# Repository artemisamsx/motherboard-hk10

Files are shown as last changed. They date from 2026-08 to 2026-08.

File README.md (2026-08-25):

# Artemisa MSX - Model HK-10 Motherboard

This repository contains the KiCad project files for the Model HK-10 motherboard, part of the **Artemisa** project.

## About Artemisa

Artemisa is a project to design new MSX-1 compatible computers using modern manufacturing
techniques while staying true to the original architecture: a Z80 CPU, discrete memory chips,
and dedicated peripheral ICs (VDP, PSG, PPI, etc.), with no FPGAs involved. The roadmap
includes several different models, each exploring different trade-offs between fidelity,
cost, and ease of assembly.

## The HK-10 model

The HK-10 is based on the **Model 101**, a prototype that was never distributed commercially.
The goal of the HK-10 is to bring that design to the general public as a homebrew-friendly
product, with the constraints and trade-offs typical of the homebrew scene.

"HK" stands for **Homebrew Kit**. The HK-10 is meant to be sold as a kit and assembled by the
user, comprising:

- The motherboard and other PCBs
- A 3D-printed PETG enclosure
- The main chips (CPU, memory, PSG, VDP)
- Passive components (resistors, capacitors, etc.)

### Features

- 2 cartridge slots
- 1 datasette (cassette) port
- 2 joystick ports
- External, cable-connected keyboard port

The HK-10 does **not** include a serial port or a printer port.

### Graphics

The graphics subsystem is implemented on separate PCBs rather than being part of the
motherboard itself, so that users can customize their video output and choose a graphics
chip (TMS9918 vs TMS9928 vs TMS9929). These graphics cards are based on the GFX-9918 card
used in the Model 101 prototype, but with a different form factor and naming, e.g.
`HKG-9918`, `HKG-9929`.

### Memory

The HK-10 uses SRAM instead of DRAM. For the memory sizes involved, SRAM is simpler, cheaper
and easier to source than DRAM, at the cost of some board space.

### Design philosophy

The HK-10 aims to be the simplest and most didactic model in the Artemisa lineup. To that
end, it avoids any programmable logic devices (PLDs, PALs, GALs, etc.) in favor of discrete
logic chips, consistent with how the original MSX computers were designed in the 1980s.

### Differences from the Model 101 prototype

- **Form factor**: the HK-10 uses a different, more compact form factor than the 101.
- **Power supply**: the HK-10 has its own integrated AC/DC adapter providing 5V, 12V and -12V,
  whereas the 101 was only powered externally at 5V.
- **Simplified circuits**: some circuits have been simplified compared to the 101, namely the
  clock generation and the power-on reset (PoR) circuit.
- **No integrated keyboard**: unlike most MSX computers (and most microcomputers of that era),
  the HK-10 does not have a keyboard built into the case. The keyboard is a separate unit
  connected via cable to a port on the motherboard.

## Repository layout

The schematic is split into sheets by functional block:

| File | Contents |
|---|---|
| `motherboard-hk10.kicad_sch` | Top-level sheet |
| `cpu.kicad_sch` | Z80 CPU |
| `ram.kicad_sch` | SRAM |
| `rom.kicad_sch` | ROM |
| `ppi.kicad_sch` | Programmable Peripheral Interface (keyboard, joysticks, cassette control) |
| `psg.kicad_sch` | Programmable Sound Generator |
| `clock.kicad_sch` | Clock generation |
| `decoding.kicad_sch` | Address decoding |
| `power.kicad_sch` | Power supply and power-on reset |
| `slots.kicad_sch` | Cartridge slots |
| `keyboard.kicad_sch` | External keyboard connector |
| `cassette.kicad_sch` | Datasette port |

`motherboard-hk10.kicad_pcb` contains the PCB layout, and `simulation/` contains SPICE
simulations used to validate specific circuits (power-on reset, clock generation, video
output filtering, etc.).

See [CHANGELOG.md](CHANGELOG.md) for a history of board revisions.

## Key components

- **Clock generator**: [Epson SG-615P / SG-531P][1], a packaged crystal oscillator (SPXO)
  used to generate the master clock.

## License

This project is licensed under the [TAPR Open Hardware License](LICENSE.txt).

---

[1]: https://www.mouser.com/datasheet/2/137/SG_615P_en-1880245.pdf "Epson SG-615P / SG-531P datasheet"

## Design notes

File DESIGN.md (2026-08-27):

# HK-10 Design Notes

This document records relevant design decisions and considerations for the HK-10 motherboard,
organized by functional area. It complements the schematics and [README.md](README.md) by
capturing the *why* behind choices that aren't obvious from the design files alone.

## Power management

### AC/DC adapter

The HK-10 integrates an AC/DC power adapter inside the enclosure rather than relying on an
external wall-wart, unlike the Model 101 prototype. The adapter is a third-party module, not
a custom design: the [Meanwell RT-50B][1] was chosen. It provides the 5V, 12V and -12V
rails required by the board.

Mains enters through a panel-mounted IEC 320 C14 inlet with an integrated fuse holder and
rocker switch, specifically the Filn AC-14-F15 (an Asian vendor part). The C14 is used
rather than a two-pole inlet so the enclosure carries a protective-earth connection, which
the RT-50B requires.

The adapter connects to the motherboard through a cable fitted with a JST connector. We
settled on **JST-XH** (2.5mm pitch, 4 positions: +5V, +12V, -12V, GND) over other JST
families such as PH: XH terminals are rated for ~3A per contact, giving headroom over PH's
~2A, and XH is the de-facto standard for RC/LiPo balance connectors, which makes it easy to
source pre-crimped cable assemblies from generic vendors rather than specialized suppliers
like Mouser or Digikey.

The pinout, matching the wire colors of the generic pre-crimped kits used, is:

| Pin | Signal | Wire color |
|---|---|---|
| 1 | GND | Black |
| 2 | +5V | Red |
| 3 | -12V | White |
| 4 | +12V | Yellow |

One caveat worth recording: off-the-shelf "JST-XH balance cables" from the RC hobby market
are typically wired with 26-28 AWG, since balance leads only carry sensing current, not
power. For this power cable we need 22 AWG (or better) so the wire itself doesn't become the
bottleneck. Pre-crimped 4-pin XH kits with 22 AWG wire are readily available on generic
retail (e.g. Amazon Spain), so this doesn't require a specialized crimping tool or sourcing
loose terminals.

With a single shared GND return, the worst-case combined return current is the sum of the
+5V, +12V and -12V draws. The MSX standard caps the cartridge slots' power budget per slot
at 300mA (+5V), 50mA (+12V) and 50mA (-12V)[3]. With the HK-10's 2 cartridge slots, and the
~500mA the motherboard itself draws on +5V (per the Model 101 prototype, which doesn't use
+12V/-12V at all), the absolute worst case is ~1.1A on +5V and 100mA each on +12V/-12V — a
combined return well within the XH terminal's ~3A rating and the 22 AWG wire's capacity, so
a single GND pin is sufficient without needing a 5-pin connector with a doubled-up return.

The RT-50B is a switching (SMPS) power supply, so its output rails can carry significant
ripple and switching noise. On its own 5V rail, this noise is prone to leaking into the VDP's
analog video output, resulting in a visibly noisy picture. To mitigate this, we are evaluating
deriving a clean 5V supply for the VDP from the RT-50B's 12V rail through a linear regulator
(7805) instead of using the RT-50B's 5V rail directly. A linear regulator rejects the
switching noise present on the 12V rail, at the cost of the extra heat dissipated by the
regulator. This is not settled yet, but the 7805 would most likely live on the HKG-99xx
graphics card rather than on the motherboard.

### Power-on reset (PoR)

The power-on reset circuit is built around the [MIC1232][2] from Microchip. It was
chosen mainly for its ease of use combined with good availability, particularly in DIP
package, which matters for a kit meant to be hand-assembled by end users.

## Clock generation

The master clock is generated with a packaged crystal oscillator IC, the Epson SG-615P /
SG-531P, instead of a discrete crystal driven by an unbuffered inverter (74HCU04) with its
typical feedback network (bias/feedback resistor, series damping resistor, and symmetric
load capacitors). The oscillator IC integrates the crystal, feedback network and load
capacitors internally and outputs a ready-made digital clock signal, which removes several
discrete components (crystal, two load capacitors, two resistors) and the oscillator gate
from the board. The divide-by-2 stage that derives `PSGCLK` from `CLK` for the PSG is
unaffected by this change.

The oscillator's `CLK` output is buffered before fanning out to the CPU, the cartridge
slots, the power-on reset sync logic and the `PSGCLK` divider, rather than driving all of
that directly from the oscillator's output pin. Buffering keeps the oscillator isolated
from a net that is exposed on the (hot-pluggable) cartridge slot connectors, and gives
some headroom against the oscillator's fairly light guaranteed output drive (`IOH` = -400
µA min. per the datasheet). The buffer is a spare gate on `U14`, a `74HC08` (quad 2-input
AND) already used for address-decoding logic, wired as a non-inverting buffer by tying one
input permanently high. This avoids adding a new IC just for buffering — none of the
existing inverter packages on the board had a spare gate, but this AND gate did. Signal
polarity doesn't matter here (nothing on this board has a phase relationship to preserve
against the raw oscillator output), so a single gate is enough; there's no need for a
second inversion. Checked against the TI SN74HC08 datasheet, this buffer neither hurts
fanout (both parts are rated for 10 LSTTL loads) nor meaningfully degrades the clock edges
(its rise/fall time is comparable to the oscillator's own, and negligible next to the
~279 ns clock period at 3.579545 MHz).

## Enclosure layout

The enclosure targets a 25x33.5cm internal perimeter. The motherboard, at 24x18cm, sits
centered and pushed against the front end of the enclosure.

On that front end are the joystick ports and the keyboard port. The cassette port sits on the
right-hand side. The cartridge slots are centered on the motherboard.

The rear end of the enclosure houses the RT-50B power supply and the HKG-99xx graphics card.
The motherboard and the graphics card are connected by a 50-pin IDC cable.

### Cartridge alignment guides

Rather than relying on a bare slot cut into the enclosure shell with a spring to guide
cartridges into their card-edge connectors (as in the Model 101 prototype), the HK-10
enclosure will include a pair of 3D-printed guide housings, one per cartridge slot. Each
housing is tub-shaped, covering the full footprint of the cartridge on top of the
motherboard with an opening for the card-edge connector, and with internal ribs matching
the notches standard on MSX cartridges to physically block reversed insertion, which could
otherwise damage the cartridge's own edge connector.

With a cartridge fully seated in its slot, there's a measured 5mm clearance between the
bottom of the cartridge shell and the motherboard PCB, which the guide housing's floor
occupies.

Each guide housing is fastened to the motherboard with 2x M3 screws, which also pass
through into the enclosure shell, tying housing, PCB and enclosure into a single rigid
assembly. This accounts for 4 of the board's mounting holes (2 per slot), placed close to
each slot connector, one at each end. Sitting directly against the connectors, these give
the slot area — the heaviest, most heavily stressed part of the board — more direct
support than a single mounting hole at the board's geometric center would, so no separate
central mounting hole is needed.

---

[1]: http://www.meanwelljapan.com/upload/pdf/RT-50/RT-50-SPEC.PDF "Meanwell RT-50B datasheet"
[2]: https://www.microchip.com/en-us/product/mic1232 "Microchip MIC1232 product page"
[3]: https://sysadminmosaic.ru/_media/msx/msx_technical_data_book/msx_technical_data_book_text.pdf "MSX Technical Data Book, section 1.5.4 Cartridge Power Capacity"

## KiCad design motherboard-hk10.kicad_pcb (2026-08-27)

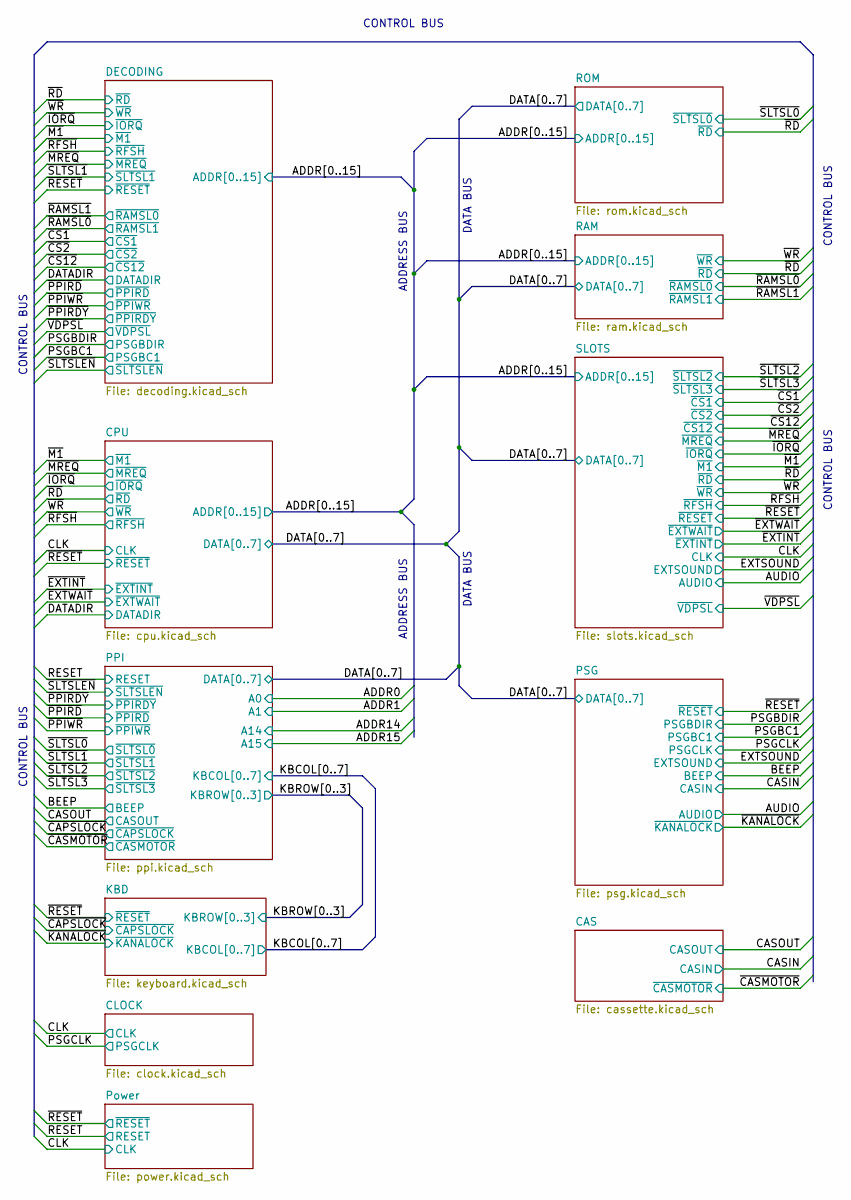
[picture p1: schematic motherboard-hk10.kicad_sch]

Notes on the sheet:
CONTROL BUS
ADDRESS BUS
DATA BUS

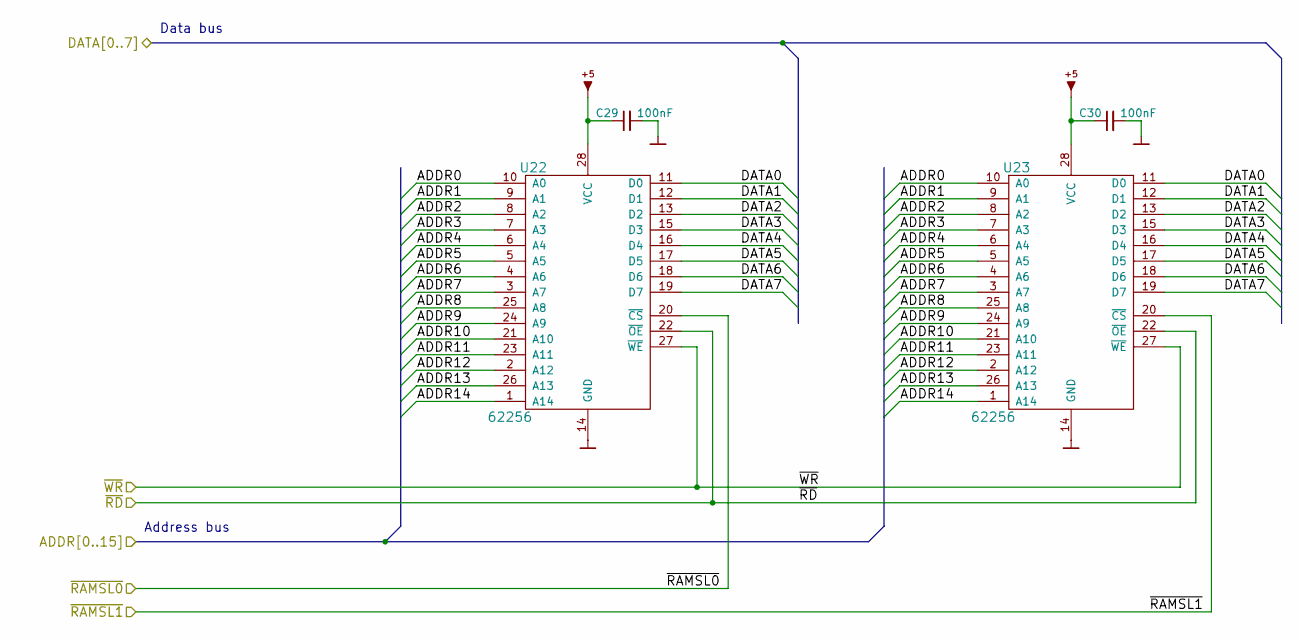
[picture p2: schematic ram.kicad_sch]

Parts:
C29, C30: 100nF; C_Disc_D5.0mm_W2.5mm_P2.50mm
U22, U23: 62256; DIP-28_W15.24mm_Socket

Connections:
/ADDR0: U22.10 (A0), U23.10 (A0); also elsewhere on the board
/ADDR1: U22.9 (A1), U23.9 (A1); also elsewhere on the board
/ADDR2: U22.8 (A2), U23.8 (A2); also elsewhere on the board
/ADDR3: U22.7 (A3), U23.7 (A3); also elsewhere on the board
/ADDR4: U22.6 (A4), U23.6 (A4); also elsewhere on the board
/ADDR5: U22.5 (A5), U23.5 (A5); also elsewhere on the board
/ADDR6: U22.4 (A6), U23.4 (A6); also elsewhere on the board
/ADDR7: U22.3 (A7), U23.3 (A7); also elsewhere on the board
/ADDR8: U22.25 (A8), U23.25 (A8); also elsewhere on the board
/ADDR9: U22.24 (A9), U23.24 (A9); also elsewhere on the board
/ADDR10: U22.21 (A10), U23.21 (A10); also elsewhere on the board
/ADDR11: U22.23 (A11), U23.23 (A11); also elsewhere on the board
/ADDR12: U22.2 (A12), U23.2 (A12); also elsewhere on the board
/ADDR13: U22.26 (A13), U23.26 (A13); also elsewhere on the board
/ADDR14: U22.1 (A14), U23.1 (A14); also elsewhere on the board
/DATA0: U22.11 (D0), U23.11 (D0); also elsewhere on the board
/DATA1: U22.12 (D1), U23.12 (D1); also elsewhere on the board
/DATA2: U22.13 (D2), U23.13 (D2); also elsewhere on the board
/DATA3: U22.15 (D3), U23.15 (D3); also elsewhere on the board
/DATA4: U22.16 (D4), U23.16 (D4); also elsewhere on the board
/DATA5: U22.17 (D5), U23.17 (D5); also elsewhere on the board
/DATA6: U22.18 (D6), U23.18 (D6); also elsewhere on the board
/DATA7: U22.19 (D7), U23.19 (D7); also elsewhere on the board
/~RAMSL0: U22.20 (~CS); also elsewhere on the board
/~RAMSL1: U23.20 (~CS); also elsewhere on the board
/~RD: U22.22 (~OE), U23.22 (~OE); also elsewhere on the board
/~WR: U22.27 (~WE), U23.27 (~WE); also elsewhere on the board
GND: C29.2, C30.2, U22.14 (GND), U23.14 (GND); also elsewhere on the board
VCC: C29.1, C30.1, U22.28 (VCC), U23.28 (VCC); also elsewhere on the board

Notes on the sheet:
Data bus
Address bus

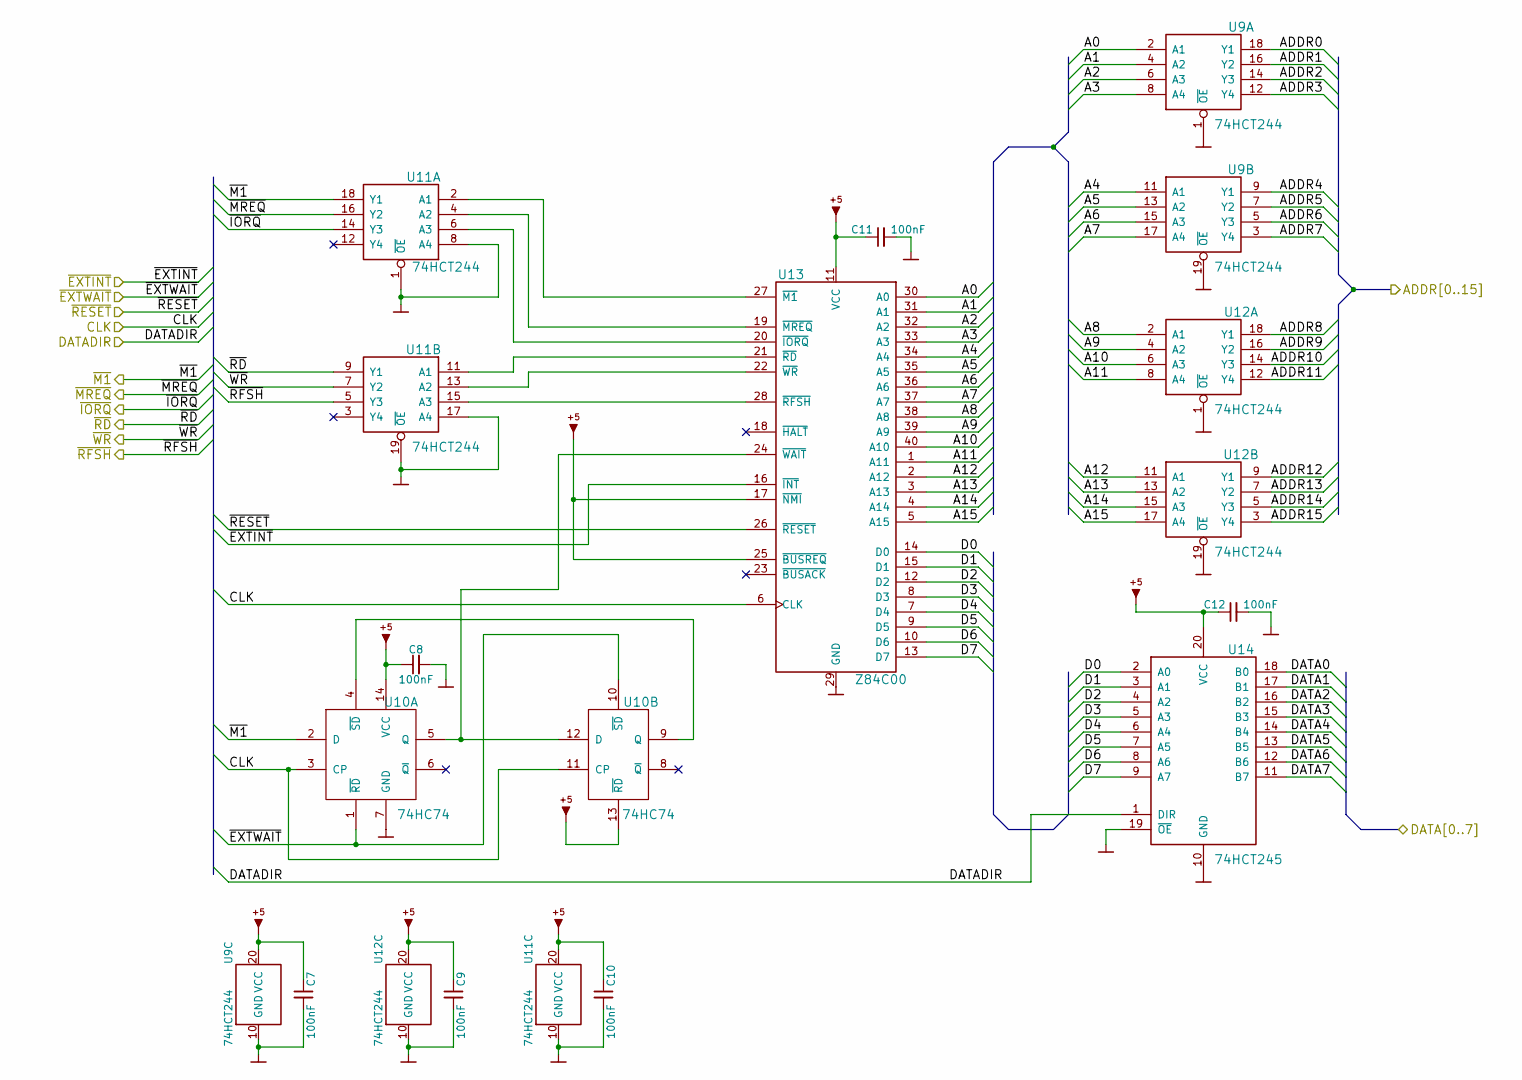
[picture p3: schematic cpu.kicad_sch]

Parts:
C7, C8, C9, C10, C11, C12: 100nF; C_Disc_D5.0mm_W2.5mm_P2.50mm
U9, U11, U12: 74HCT244; DIP-20_W7.62mm
U10: 74HC74; DIP-14_W7.62mm
U13: Z84C00; DIP-40_W15.24mm_Socket
U14: 74HCT245; DIP-20_W7.62mm

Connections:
/ADDR0: U9.18 (Y1); also elsewhere on the board
/ADDR1: U9.16 (Y2); also elsewhere on the board
/ADDR2: U9.14 (Y3); also elsewhere on the board
/ADDR3: U9.12 (Y4); also elsewhere on the board
/ADDR4: U9.9 (Y1); also elsewhere on the board
/ADDR5: U9.7 (Y2); also elsewhere on the board
/ADDR6: U9.5 (Y3); also elsewhere on the board
/ADDR7: U9.3 (Y4); also elsewhere on the board
/ADDR8: U12.18 (Y1); also elsewhere on the board
/ADDR9: U12.16 (Y2); also elsewhere on the board
/ADDR10: U12.14 (Y3); also elsewhere on the board
/ADDR11: U12.12 (Y4); also elsewhere on the board
/ADDR12: U12.9 (Y1); also elsewhere on the board
/ADDR13: U12.7 (Y2); also elsewhere on the board
/ADDR14: U12.5 (Y3); also elsewhere on the board
/ADDR15: U12.3 (Y4); also elsewhere on the board
/CLK: U10.3 (CP), U10.11 (CP), U13.6 (CLK); also elsewhere on the board
/CPU/A0: U9.2 (A1), U13.30 (A0)
/CPU/A1: U9.4 (A2), U13.31 (A1)
/CPU/A2: U9.6 (A3), U13.32 (A2)
/CPU/A3: U9.8 (A4), U13.33 (A3)
/CPU/A4: U9.11 (A1), U13.34 (A4)
/CPU/A5: U9.13 (A2), U13.35 (A5)
/CPU/A6: U9.15 (A3), U13.36 (A6)
/CPU/A7: U9.17 (A4), U13.37 (A7)
/CPU/A8: U12.2 (A1), U13.38 (A8)
/CPU/A9: U12.4 (A2), U13.39 (A9)
/CPU/A10: U12.6 (A3), U13.40 (A10)
/CPU/A11: U12.8 (A4), U13.1 (A11)
/CPU/A12: U12.11 (A1), U13.2 (A12)
/CPU/A13: U12.13 (A2), U13.3 (A13)
/CPU/A14: U12.15 (A3), U13.4 (A14)
/CPU/A15: U12.17 (A4), U13.5 (A15)
/CPU/D0: U13.14 (D0), U14.2 (A0)
/CPU/D1: U13.15 (D1), U14.3 (A1)
/CPU/D2: U13.12 (D2), U14.4 (A2)
/CPU/D3: U13.8 (D3), U14.5 (A3)
/CPU/D4: U13.7 (D4), U14.6 (A4)
/CPU/D5: U13.9 (D5), U14.7 (A5)
/CPU/D6: U13.10 (D6), U14.8 (A6)
/CPU/D7: U13.13 (D7), U14.9 (A7)
/DATA0: U14.18 (B0); also elsewhere on the board
/DATA1: U14.17 (B1); also elsewhere on the board
/DATA2: U14.16 (B2); also elsewhere on the board
/DATA3: U14.15 (B3); also elsewhere on the board
/DATA4: U14.14 (B4); also elsewhere on the board
/DATA5: U14.13 (B5); also elsewhere on the board
/DATA6: U14.12 (B6); also elsewhere on the board
/DATA7: U14.11 (B7); also elsewhere on the board
/DATADIR: U14.1 (DIR); also elsewhere on the board
/~EXTINT: U13.16 (~INT); also elsewhere on the board
/~EXTWAIT: U10.1 (~RD), U10.10 (~SD); also elsewhere on the board
/~IORQ: U11.14 (Y3); also elsewhere on the board
/~M1: U10.2 (D), U11.18 (Y1); also elsewhere on the board
/~MREQ: U11.16 (Y2); also elsewhere on the board
/~RD: U11.9 (Y1); also elsewhere on the board
/~RESET: U13.26 (~RESET); also elsewhere on the board
/~RFSH: U11.5 (Y3); also elsewhere on the board
/~WR: U11.7 (Y2); also elsewhere on the board
GND: C7.2, C8.2, C9.2, C10.2, C11.2, C12.2, U9.1 (~OE), U9.10 (GND), U9.19 (~OE), U10.7 (GND), U11.1 (~OE), U11.8 (A4), U11.10 (GND), U11.17 (A4), U11.19 (~OE), U12.1 (~OE), U12.10 (GND), U12.19 (~OE), U13.29 (GND), U14.10 (GND), U14.19 (~OE); also elsewhere on the board
unnamed: U10.5 (Q), U10.12 (D), U13.24 (~WAIT)
unnamed: U10.4 (~SD), U10.9 (Q)
unnamed: U11.2 (A1), U13.27 (~M1)
unnamed: U11.4 (A2), U13.19 (~MREQ)
unnamed: U11.6 (A3), U13.20 (~IORQ)
unnamed: U11.11 (A1), U13.21 (~RD)
unnamed: U11.13 (A2), U13.22 (~WR)
unnamed: U11.15 (A3), U13.28 (~RFSH)
VCC: C7.1, C8.1, C9.1, C10.1, C11.1, C12.1, U9.20 (VCC), U10.13 (~RD), U10.14 (VCC), U11.20 (VCC), U12.20 (VCC), U13.11 (VCC), U13.17 (~NMI), U13.25 (~BUSREQ), U14.20 (VCC); also elsewhere on the board

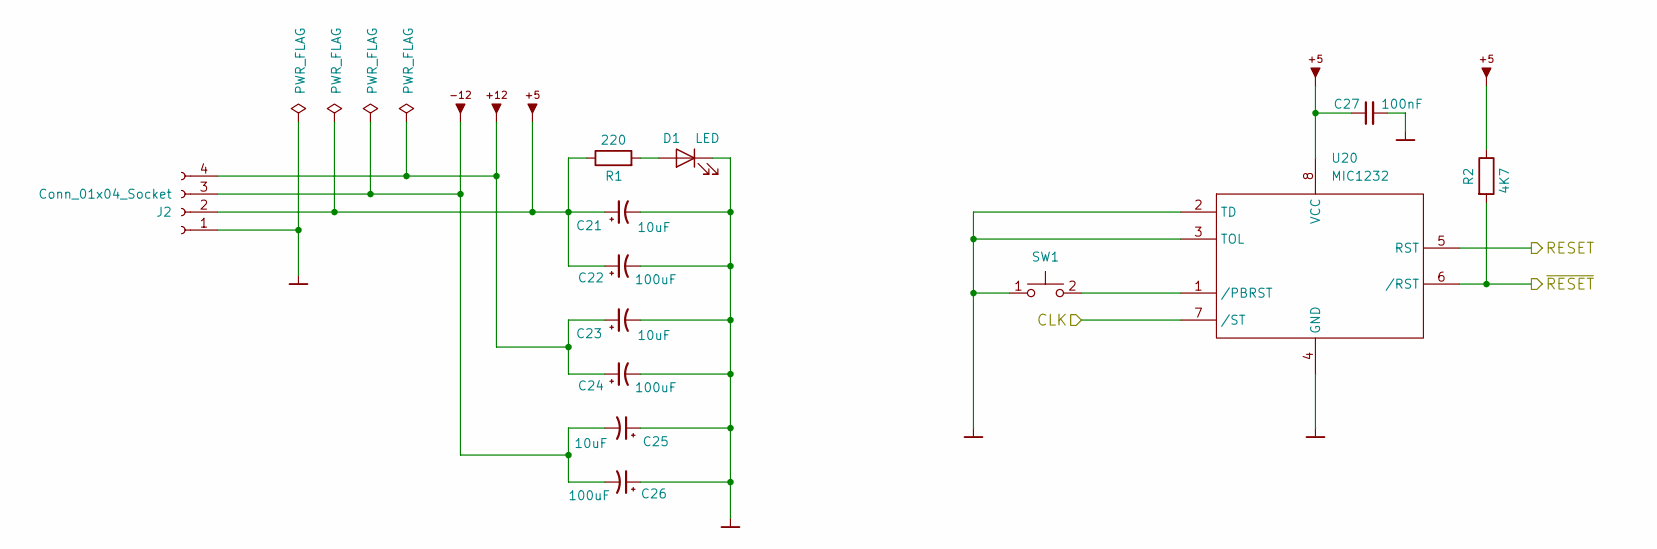
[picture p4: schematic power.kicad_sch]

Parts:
C21, C23, C25: 10uF; CP_Radial_D4.0mm_P2.00mm
C22, C24, C26: 100uF; CP_Radial_D5.0mm_P2.50mm
C27: 100nF; C_Disc_D5.0mm_W2.5mm_P2.50mm
D1: LED; PinHeader_1x02_P2.54mm_Vertical
J2: Conn_01x04_Socket; JST_XH_B4B-XH-A_1x04_P2.50mm_Vertical
R1: 220; R_Axial_DIN0207_L6.3mm_D2.5mm_P10.16mm_Horizontal
R2: 4K7; R_Axial_DIN0207_L6.3mm_D2.5mm_P10.16mm_Horizontal
SW1: Push_button; Push_button_angled
U20: MIC1232; DIP-8_W7.62mm

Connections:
12V: C23.1, C24.1, J2.4; also elsewhere on the board
-12V: C25.2, C26.2, J2.3; also elsewhere on the board
/CLK: U20.7 (/ST); also elsewhere on the board
/RESET: U20.5 (RST); also elsewhere on the board
/~RESET: R2.2, U20.6 (/RST); also elsewhere on the board
GND: C21.2, C22.2, C23.2, C24.2, C25.1, C26.1, C27.2, D1.2 (K), J2.1, SW1.1, U20.2 (TD), U20.3 (TOL), U20.4 (GND); also elsewhere on the board
unnamed: D1.1 (A), R1.2
unnamed: SW1.2, U20.1 (/PBRST)
VCC: C21.1, C22.1, C27.1, J2.2, R1.1, R2.1, U20.8 (VCC); also elsewhere on the board

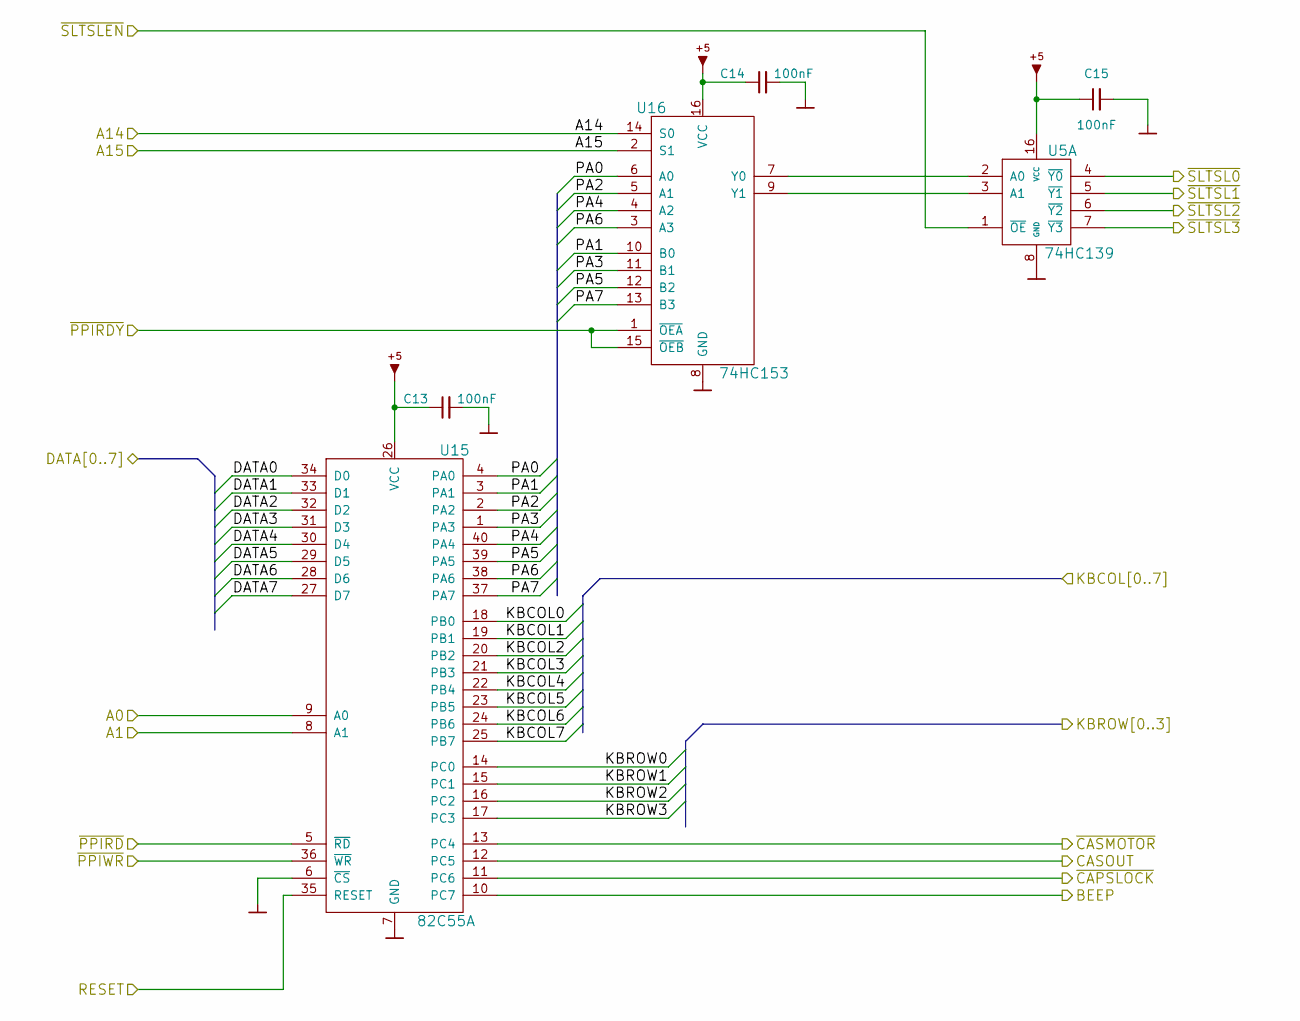
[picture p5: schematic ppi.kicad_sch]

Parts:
C13, C14, C15: 100nF; C_Disc_D5.0mm_W2.5mm_P2.50mm
U5: 74HC139; DIP-16_W7.62mm
U15: 82C55A; DIP-40_W15.24mm_Socket
U16: 74HC153; DIP-16_W7.62mm

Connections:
/ADDR0: U15.9 (A0); also elsewhere on the board
/ADDR1: U15.8 (A1); also elsewhere on the board
/ADDR14: U16.14 (S0); also elsewhere on the board
/ADDR15: U16.2 (S1); also elsewhere on the board
/BEEP: U15.10 (PC7); also elsewhere on the board
/CASOUT: U15.12 (PC5); also elsewhere on the board
/DATA0: U15.34 (D0); also elsewhere on the board
/DATA1: U15.33 (D1); also elsewhere on the board
/DATA2: U15.32 (D2); also elsewhere on the board
/DATA3: U15.31 (D3); also elsewhere on the board
/DATA4: U15.30 (D4); also elsewhere on the board
/DATA5: U15.29 (D5); also elsewhere on the board
/DATA6: U15.28 (D6); also elsewhere on the board
/DATA7: U15.27 (D7); also elsewhere on the board
/KBCOL0: U15.18 (PB0); also elsewhere on the board
/KBCOL1: U15.19 (PB1); also elsewhere on the board
/KBCOL2: U15.20 (PB2); also elsewhere on the board
/KBCOL3: U15.21 (PB3); also elsewhere on the board
/KBCOL4: U15.22 (PB4); also elsewhere on the board
/KBCOL5: U15.23 (PB5); also elsewhere on the board
/KBCOL6: U15.24 (PB6); also elsewhere on the board
/KBCOL7: U15.25 (PB7); also elsewhere on the board
/KBROW0: U15.14 (PC0); also elsewhere on the board
/KBROW1: U15.15 (PC1); also elsewhere on the board
/KBROW2: U15.16 (PC2); also elsewhere on the board
/KBROW3: U15.17 (PC3); also elsewhere on the board
/PPI/PA0: U15.4 (PA0), U16.6 (A0)
/PPI/PA1: U15.3 (PA1), U16.10 (B0)
/PPI/PA2: U15.2 (PA2), U16.5 (A1)
/PPI/PA3: U15.1 (PA3), U16.11 (B1)
/PPI/PA4: U15.40 (PA4), U16.4 (A2)
/PPI/PA5: U15.39 (PA5), U16.12 (B2)
/PPI/PA6: U15.38 (PA6), U16.3 (A3)
/PPI/PA7: U15.37 (PA7), U16.13 (B3)
/RESET: U15.35 (RESET); also elsewhere on the board
/~CAPSLOCK: U15.11 (PC6); also elsewhere on the board
/~CASMOTOR: U15.13 (PC4); also elsewhere on the board
/~PPIRDY: U16.1 (~OEA), U16.15 (~OEB); also elsewhere on the board
/~PPIRD: U15.5 (~RD); also elsewhere on the board
/~PPIWR: U15.36 (~WR); also elsewhere on the board
/~SLTSL0: U5.4 (~Y0); also elsewhere on the board
/~SLTSL1: U5.5 (~Y1); also elsewhere on the board
/~SLTSL2: U5.6 (~Y2); also elsewhere on the board
/~SLTSL3: U5.7 (~Y3); also elsewhere on the board
/~SLTSLEN: U5.1 (~OE); also elsewhere on the board
GND: C13.2, C14.2, C15.2, U5.8 (GND), U15.6 (~CS), U15.7 (GND), U16.8 (GND); also elsewhere on the board
unnamed: U5.2 (A0), U16.7 (Y0)
unnamed: U5.3 (A1), U16.9 (Y1)
VCC: C13.1, C14.1, C15.1, U5.16 (VCC), U15.26 (VCC), U16.16 (VCC); also elsewhere on the board

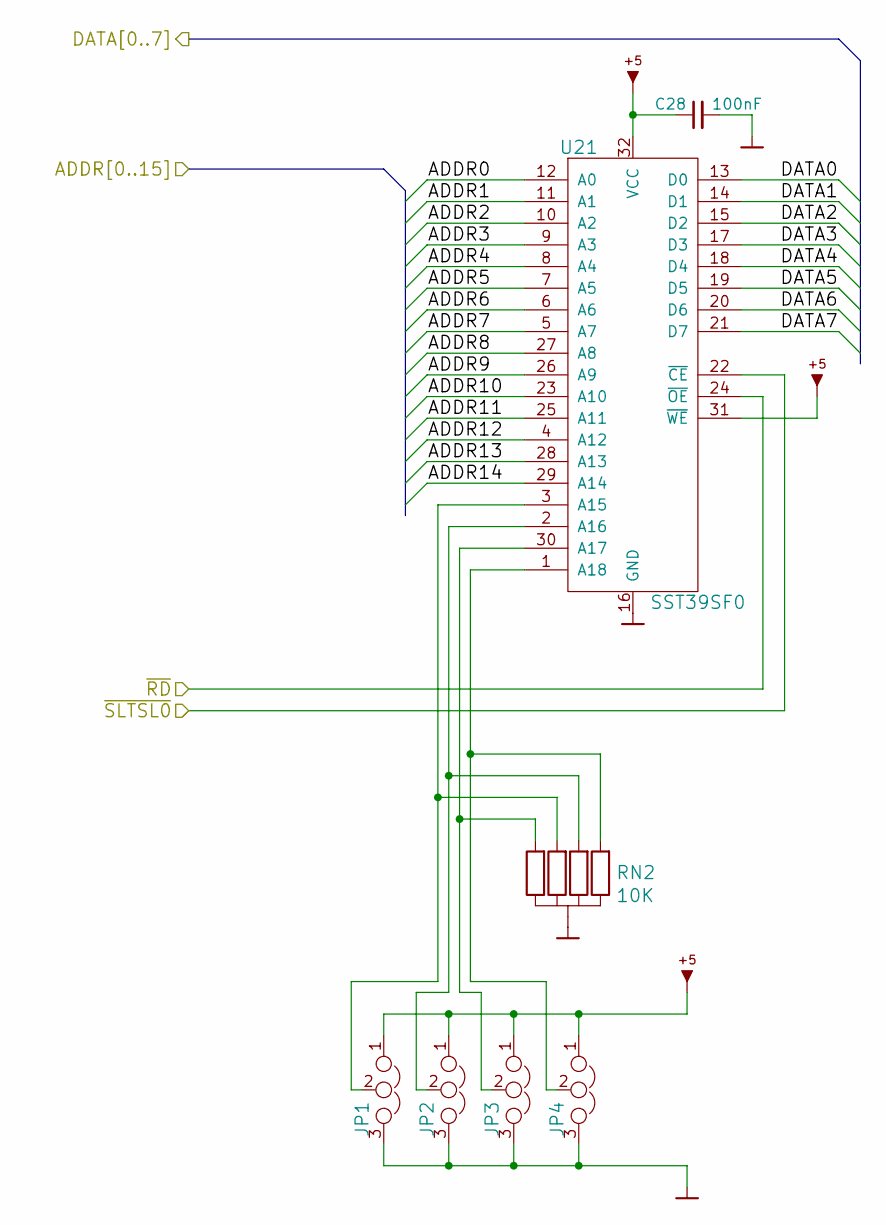
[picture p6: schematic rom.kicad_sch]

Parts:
C28: 100nF; C_Disc_D5.0mm_W2.5mm_P2.50mm
JP1, JP2, JP3, JP4: Jumper; PinHeader_1x03_P2.54mm_Vertical
RN2: 10K; R_Array_SIP5
U21: SST39SF0; DIP-32_W15.24mm_Socket

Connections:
/ADDR0: U21.12 (A0); also elsewhere on the board
/ADDR1: U21.11 (A1); also elsewhere on the board
/ADDR2: U21.10 (A2); also elsewhere on the board
/ADDR3: U21.9 (A3); also elsewhere on the board
/ADDR4: U21.8 (A4); also elsewhere on the board
/ADDR5: U21.7 (A5); also elsewhere on the board
/ADDR6: U21.6 (A6); also elsewhere on the board
/ADDR7: U21.5 (A7); also elsewhere on the board
/ADDR8: U21.27 (A8); also elsewhere on the board
/ADDR9: U21.26 (A9); also elsewhere on the board
/ADDR10: U21.23 (A10); also elsewhere on the board
/ADDR11: U21.25 (A11); also elsewhere on the board
/ADDR12: U21.4 (A12); also elsewhere on the board
/ADDR13: U21.28 (A13); also elsewhere on the board
/ADDR14: U21.29 (A14); also elsewhere on the board
/DATA0: U21.13 (D0); also elsewhere on the board
/DATA1: U21.14 (D1); also elsewhere on the board
/DATA2: U21.15 (D2); also elsewhere on the board
/DATA3: U21.17 (D3); also elsewhere on the board
/DATA4: U21.18 (D4); also elsewhere on the board
/DATA5: U21.19 (D5); also elsewhere on the board
/DATA6: U21.20 (D6); also elsewhere on the board
/DATA7: U21.21 (D7); also elsewhere on the board
/~RD: U21.24 (~OE); also elsewhere on the board
/~SLTSL0: U21.22 (~CE); also elsewhere on the board
GND: C28.2, JP1.3, JP2.3, JP3.3, JP4.3, RN2.1, U21.16 (GND); also elsewhere on the board
unnamed: JP1.2, RN2.4, U21.3 (A15)
unnamed: JP2.2, RN2.3, U21.2 (A16)
unnamed: JP3.2, RN2.5, U21.30 (A17)
unnamed: JP4.2, RN2.2, U21.1 (A18)
VCC: C28.1, JP1.1, JP2.1, JP3.1, JP4.1, U21.31 (~WE), U21.32 (VCC); also elsewhere on the board

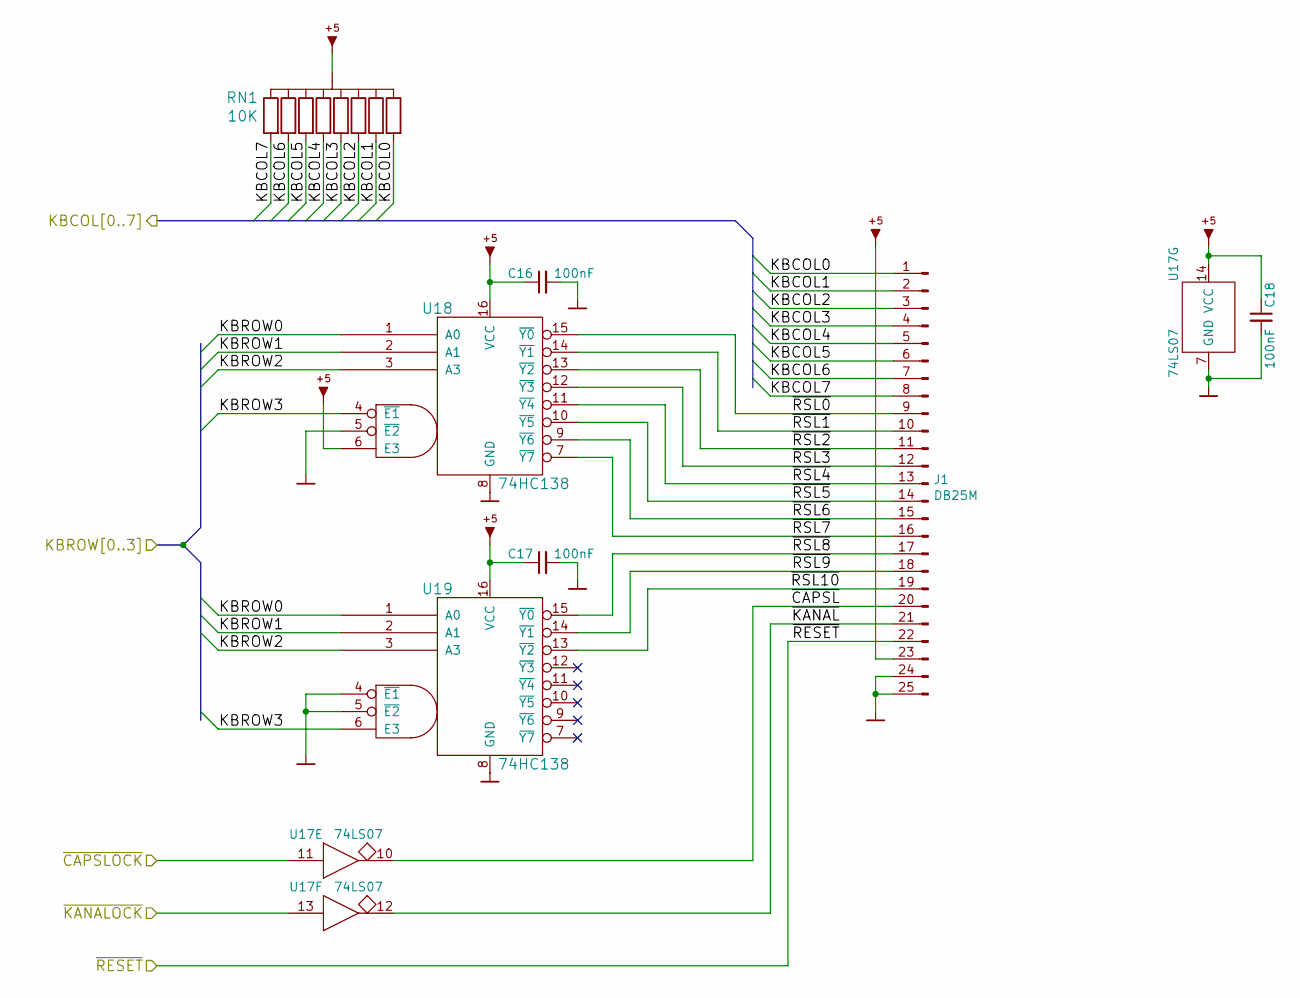
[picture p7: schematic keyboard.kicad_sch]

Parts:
C16, C17, C18: 100nF; C_Disc_D5.0mm_W2.5mm_P2.50mm
J1: DB25M
RN1: 10K; R_Array_SIP9
U17: 74LS07; DIP-14_W7.62mm
U18, U19: 74HC138; DIP-16_W7.62mm

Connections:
/KBCOL0: J1.1, RN1.2; also elsewhere on the board
/KBCOL1: J1.2, RN1.3; also elsewhere on the board
/KBCOL2: J1.3, RN1.4; also elsewhere on the board
/KBCOL3: J1.4, RN1.5; also elsewhere on the board
/KBCOL4: J1.5, RN1.6; also elsewhere on the board
/KBCOL5: J1.6, RN1.7; also elsewhere on the board
/KBCOL6: J1.7, RN1.8; also elsewhere on the board
/KBCOL7: J1.8, RN1.9; also elsewhere on the board
/KBD/~CAPSL: J1.20, U17.10
/KBD/~KANAL: J1.21, U17.12
/KBD/~RSL0: J1.9, U18.15 (~Y0)
/KBD/~RSL1: J1.10, U18.14 (~Y1)
/KBD/~RSL2: J1.11, U18.13 (~Y2)
/KBD/~RSL3: J1.12, U18.12 (~Y3)
/KBD/~RSL4: J1.13, U18.11 (~Y4)
/KBD/~RSL5: J1.14, U18.10 (~Y5)
/KBD/~RSL6: J1.15, U18.9 (~Y6)
/KBD/~RSL7: J1.16, U18.7 (~Y7)
/KBD/~RSL8: J1.17, U19.15 (~Y0)
/KBD/~RSL9: J1.18, U19.14 (~Y1)
/KBD/~RSL10: J1.19, U19.13 (~Y2)
/KBROW0: U18.1 (A0), U19.1 (A0); also elsewhere on the board
/KBROW1: U18.2 (A1), U19.2 (A1); also elsewhere on the board
/KBROW2: U18.3 (A3), U19.3 (A3); also elsewhere on the board
/KBROW3: U18.4 (~E1), U19.6 (E3); also elsewhere on the board
/~CAPSLOCK: U17.11; also elsewhere on the board
/~KANALOCK: U17.13; also elsewhere on the board
/~RESET: J1.22; also elsewhere on the board
GND: C16.2, C17.2, C18.2, J1.24, J1.25, U17.7 (GND), U18.5 (~E2), U18.8 (GND), U19.4 (~E1), U19.5 (~E2), U19.8 (GND); also elsewhere on the board
VCC: C16.1, C17.1, C18.1, J1.23, RN1.1, U17.14 (VCC), U18.6 (E3), U18.16 (VCC), U19.16 (VCC); also elsewhere on the board

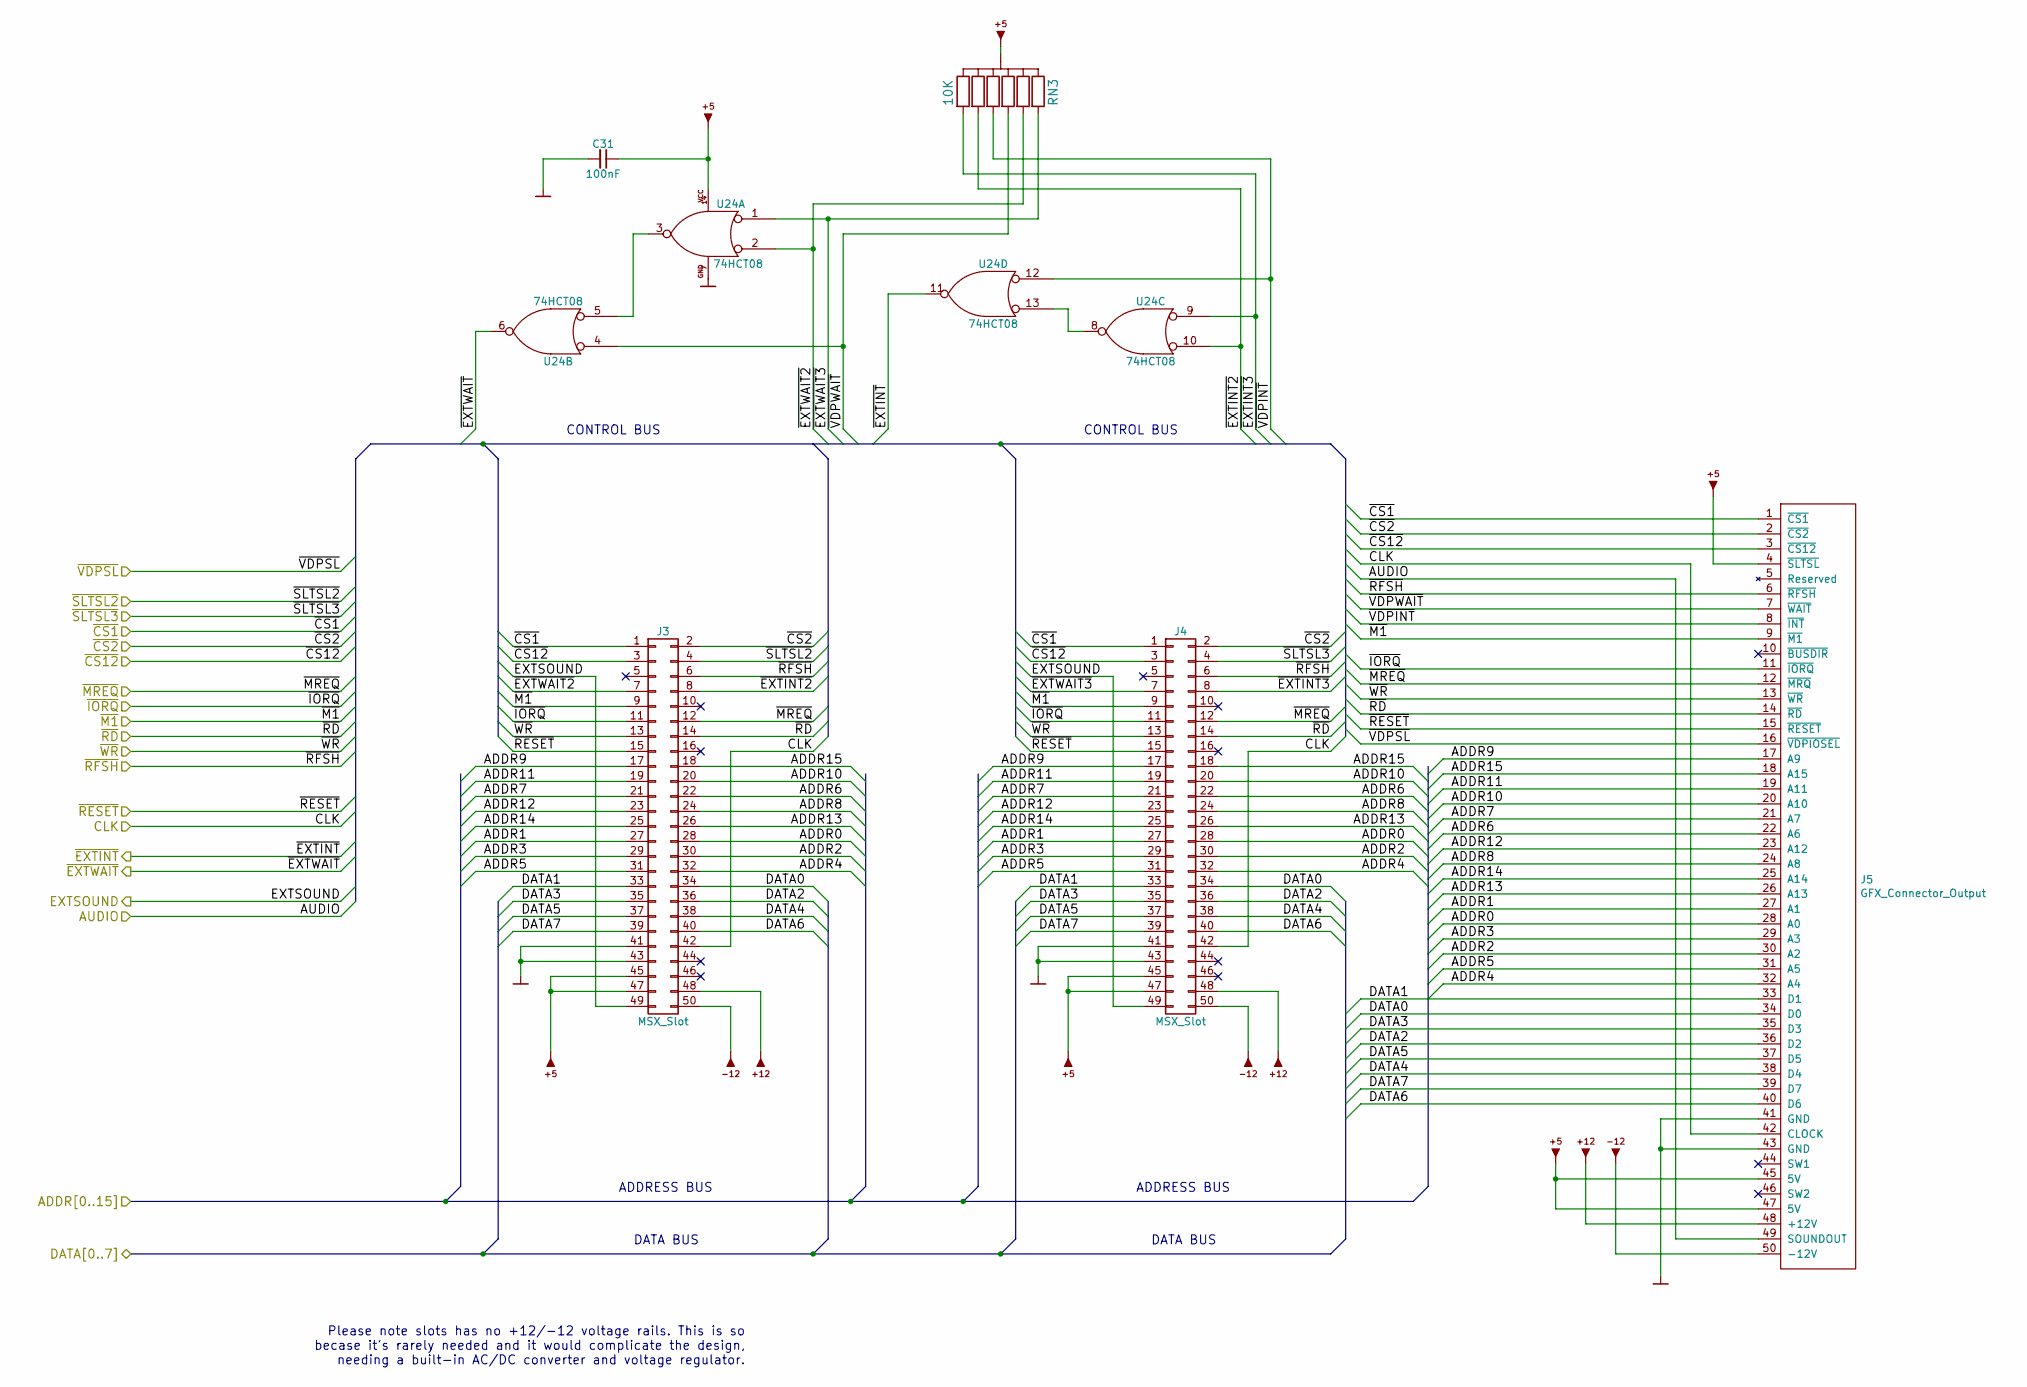
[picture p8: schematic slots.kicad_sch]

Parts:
C31: 100nF; C_Disc_D5.0mm_W2.5mm_P2.50mm
J3, J4: MSX_Slot; Slot_conn
J5: GFX_Connector_Output; IDC-Header_2x25_P2.54mm_Vertical
RN3: 10K; R_Array_SIP7
U24: 74HCT08; DIP-14_W7.62mm

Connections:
12V: J3.48, J4.48, J5.48 (+12V); also elsewhere on the board
-12V: J3.50, J4.50, J5.50 (-12V); also elsewhere on the board
/ADDR0: J3.28, J4.28, J5.28 (A0); also elsewhere on the board
/ADDR1: J3.27, J4.27, J5.27 (A1); also elsewhere on the board
/ADDR2: J3.30, J4.30, J5.30 (A2); also elsewhere on the board
/ADDR3: J3.29, J4.29, J5.29 (A3); also elsewhere on the board
/ADDR4: J3.32, J4.32, J5.32 (A4); also elsewhere on the board
/ADDR5: J3.31, J4.31, J5.31 (A5); also elsewhere on the board
/ADDR6: J3.22, J4.22, J5.22 (A6); also elsewhere on the board
/ADDR7: J3.21, J4.21, J5.21 (A7); also elsewhere on the board
/ADDR8: J3.24, J4.24, J5.24 (A8); also elsewhere on the board
/ADDR9: J3.17, J4.17, J5.17 (A9); also elsewhere on the board
/ADDR10: J3.20, J4.20, J5.20 (A10); also elsewhere on the board
/ADDR11: J3.19, J4.19, J5.19 (A11); also elsewhere on the board
/ADDR12: J3.23, J4.23, J5.23 (A12); also elsewhere on the board
/ADDR13: J3.26, J4.26, J5.26 (A13); also elsewhere on the board
/ADDR14: J3.25, J4.25, J5.25 (A14); also elsewhere on the board
/ADDR15: J3.18, J4.18, J5.18 (A15); also elsewhere on the board
/AUDIO: J5.49 (SOUNDOUT); also elsewhere on the board
/CLK: J3.42, J4.42, J5.42 (CLOCK); also elsewhere on the board
/DATA0: J3.34, J4.34, J5.34 (D0); also elsewhere on the board
/DATA1: J3.33, J4.33, J5.33 (D1); also elsewhere on the board
/DATA2: J3.36, J4.36, J5.36 (D2); also elsewhere on the board
/DATA3: J3.35, J4.35, J5.35 (D3); also elsewhere on the board
/DATA4: J3.38, J4.38, J5.38 (D4); also elsewhere on the board
/DATA5: J3.37, J4.37, J5.37 (D5); also elsewhere on the board
/DATA6: J3.40, J4.40, J5.40 (D6); also elsewhere on the board
/DATA7: J3.39, J4.39, J5.39 (D7); also elsewhere on the board
/EXTSOUND: J3.49, J4.49; also elsewhere on the board
/SLOTS/~EXTINT2: J3.8, RN3.3, U24.10
/SLOTS/~EXTINT3: J4.8, RN3.2, U24.9
/SLOTS/~EXTWAIT2: J3.7, RN3.6, U24.2
/SLOTS/~EXTWAIT3: J4.7, RN3.7, U24.1
/SLOTS/~VDPINT: J5.8 (~INT), RN3.4, U24.12
/SLOTS/~VDPWAIT: J5.7 (~WAIT), RN3.5, U24.4
/~CS1: J3.1, J4.1, J5.1 (~CS1); also elsewhere on the board
/~CS2: J3.2, J4.2, J5.2 (~CS2); also elsewhere on the board
/~CS12: J3.3, J4.3, J5.3 (~CS12); also elsewhere on the board
/~EXTINT: U24.11; also elsewhere on the board
/~EXTWAIT: U24.6; also elsewhere on the board
/~IORQ: J3.11, J4.11, J5.11 (~IORQ); also elsewhere on the board
/~M1: J3.9, J4.9, J5.9 (~M1); also elsewhere on the board
/~MREQ: J3.12, J4.12, J5.12 (~MRQ); also elsewhere on the board
/~RD: J3.14, J4.14, J5.14 (~RD); also elsewhere on the board
/~RESET: J3.15, J4.15, J5.15 (~RESET); also elsewhere on the board
/~RFSH: J3.6, J4.6, J5.6 (~RFSH); also elsewhere on the board
/~SLTSL2: J3.4; also elsewhere on the board
/~SLTSL3: J4.4; also elsewhere on the board
/~VDPSL: J5.16 (~VDPIOSEL); also elsewhere on the board
/~WR: J3.13, J4.13, J5.13 (~WR); also elsewhere on the board
GND: C31.2, J3.41, J3.43, J4.41, J4.43, J5.41 (GND), J5.43 (GND), U24.7 (GND); also elsewhere on the board
unnamed: U24.3, U24.5
unnamed: U24.8, U24.13
VCC: C31.1, J3.45, J3.47, J4.45, J4.47, J5.4 (~SLTSL), J5.45 (5V), J5.47 (5V), RN3.1, U24.14 (VCC); also elsewhere on the board

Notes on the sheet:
ADDRESS BUS
DATA BUS
CONTROL BUS
Please note slots has no +12/-12 voltage rails. This is so becase it's rarely needed and it would complicate the design, needing a built-in AC/DC converter and voltage regulator.

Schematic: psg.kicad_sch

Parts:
C32, C33, C35: 10u; CP_Radial_D4.0mm_P2.00mm
C34, C36, C37: 100nF; C_Disc_D5.0mm_W2.5mm_P2.50mm
J6, J7: CONN_JOY; Joystick_conn
R3: 20k; R_Axial_DIN0207_L6.3mm_D2.5mm_P10.16mm_Horizontal
R4: 4k7; R_Axial_DIN0207_L6.3mm_D2.5mm_P10.16mm_Horizontal
R5: 2k7; R_Axial_DIN0207_L6.3mm_D2.5mm_P10.16mm_Horizontal
R6: 470; R_Axial_DIN0207_L6.3mm_D2.5mm_P10.16mm_Horizontal
R7, R8: 10K; R_Axial_DIN0207_L6.3mm_D2.5mm_P10.16mm_Horizontal
RN4: 10K; R_Array_SIP9
RN5: 10K; R_Array_SIP5
U17: 74LS07; DIP-14_W7.62mm
U25: AY-3-8910; DIP-40_W15.24mm_Socket
U26, U27: 74HC157; DIP-16_W7.62mm

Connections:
/AUDIO: R3.2, R4.2, R5.2; also elsewhere on the board
/BEEP: C32.1; also elsewhere on the board
/CASIN: U25.14 (IOA7); also elsewhere on the board
/DATA0: U25.37 (DA0); also elsewhere on the board
/DATA1: U25.36 (DA1); also elsewhere on the board
/DATA2: U25.35 (DA2); also elsewhere on the board
/DATA3: U25.34 (DA3); also elsewhere on the board
/DATA4: U25.33 (DA4); also elsewhere on the board
/DATA5: U25.32 (DA5); also elsewhere on the board
/DATA6: U25.31 (DA6); also elsewhere on the board
/DATA7: U25.30 (DA7); also elsewhere on the board
/EXTSOUND: C33.1; also elsewhere on the board
/PSG/IOA0: U25.21 (IOA0), U26.4 (Y0)
/PSG/IOA1: U25.20 (IOA1), U26.7 (Y1)
/PSG/IOA2: U25.19 (IOA2), U26.9 (Y2)
/PSG/IOA3: U25.18 (IOA3), U26.12 (Y3)
/PSG/IOA4: U25.17 (IOA4), U27.4 (Y0)
/PSG/IOA5: U25.16 (IOA5), U27.7 (Y1)
/PSG/IOB0: U17.1, U25.13 (IOB0)
/PSG/IOB1: U17.3, U25.12 (IOB1)
/PSG/IOB2: U17.5, U25.11 (IOB2)
/PSG/IOB3: U17.9, U25.10 (IOB3)
/PSG/IOB4: J6.8, U25.9 (IOB4)
/PSG/IOB5: J7.8, U25.8 (IOB5)
/PSG/IOB6: U25.7 (IOB6), U26.1 (S), U27.1 (S)
/PSG/JOYA1: J6.1 (UP), RN4.9, U26.2 (A0)
/PSG/JOYA2: J6.2 (DOWN), RN4.8, U26.5 (A1)
/PSG/JOYA3: J6.3 (LEFT), RN4.7, U26.11 (A2)
/PSG/JOYA4: J6.4 (RIGHT), RN4.6, U26.14 (A3)
/PSG/JOYA6: J6.6 (TRIG1), RN5.5, U17.8, U27.2 (A0)
/PSG/JOYA7: J6.7 (TRIG2), RN5.4, U17.6, U27.5 (A1)
/PSG/JOYB1: J7.1 (UP), RN4.5, U26.3 (B0)
/PSG/JOYB2: J7.2 (DOWN), RN4.4, U26.6 (B1)
/PSG/JOYB3: J7.3 (LEFT), RN4.3, U26.10 (B2)
/PSG/JOYB4: J7.4 (RIGHT), RN4.2, U26.13 (B3)
/PSG/JOYB6: J7.6 (TRIG1), RN5.3, U17.4, U27.3 (B0)
/PSG/JOYB7: J7.7 (TRIG2), RN5.2, U17.2, U27.6 (B1)
/PSGBC1: U25.29 (BC1); also elsewhere on the board
/PSGBDIR: U25.27 (BDIR); also elsewhere on the board
/PSGCLK: U25.22 (CLK); also elsewhere on the board
/~KANALOCK: R7.1, U25.6 (IOB7); also elsewhere on the board
/~RESET: U25.23 (~RESET); also elsewhere on the board
GND: C34.2, C36.2, C37.2, J6.9 (GND), J7.9 (GND), R6.2, R7.2, U25.1 (GND), U25.24 (~A9), U26.8 (GND), U26.15 (~E), U27.8 (GND), U27.10 (B2), U27.11 (A2), U27.13 (B3), U27.14 (A3), U27.15 (~E); also elsewhere on the board
unnamed: C32.2, R3.1
unnamed: C33.2, R4.1
unnamed: C35.2, R5.1
unnamed: C35.1, R6.1, U25.3 (B), U25.4 (A), U25.38 (C)
unnamed: R8.2, U25.15 (IOA6)
VCC: C34.1, C36.1, C37.1, J6.5 (VCC), J7.5 (VCC), R8.1, RN4.1, RN5.1, U25.25 (A8), U25.28 (BC2), U25.40 (VCC), U26.16 (VCC), U27.16 (VCC); also elsewhere on the board

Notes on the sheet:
This just mixes the three sound sources into a single line without amplifying. This should provide a reasonably good gain for output. Otherwise, a LM386 amplifier IC should be used instead.

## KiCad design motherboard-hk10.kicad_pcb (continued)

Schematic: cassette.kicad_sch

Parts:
C38, C42: 1uF; CP_Radial_D4.0mm_P2.00mm
C39, C41: 22nF; C_Disc_D3.0mm_W2.0mm_P2.50mm
C40: 100nF; C_Disc_D5.0mm_W2.5mm_P2.50mm
D2: 1N4448; D_DO-35_SOD27_P7.62mm_Horizontal
J8: DIN8
K1: Relay; Relay_SPDT_Omron-G5LE-1
Q1: 2N2907; TO92
R9: 1k; R_Axial_DIN0207_L6.3mm_D2.5mm_P10.16mm_Horizontal
R10, R12, R14: 4k7; R_Axial_DIN0207_L6.3mm_D2.5mm_P10.16mm_Horizontal
R11: 2k2; R_Axial_DIN0207_L6.3mm_D2.5mm_P10.16mm_Horizontal
R13: 100; R_Axial_DIN0207_L6.3mm_D2.5mm_P10.16mm_Horizontal
R15: 220k; R_Axial_DIN0207_L6.3mm_D2.5mm_P10.16mm_Horizontal
R16: 10k; R_Axial_DIN0207_L6.3mm_D2.5mm_P10.16mm_Horizontal
R17, R18: 2k7; R_Axial_DIN0207_L6.3mm_D2.5mm_P10.16mm_Horizontal
U28: LM311; DIP-8_W7.62mm

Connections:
/CASIN: R9.1, U28.7 (COLOUT); also elsewhere on the board
/CASOUT: C38.1; also elsewhere on the board
/~CASMOTOR: R11.2; also elsewhere on the board
GND: C39.2, C40.2, C42.2, J8.1, J8.2, J8.3, J8.8, Q1.1 (1C), R13.1, R18.1, U28.1 (EMITOUT), U28.4 (GND); also elsewhere on the board
unnamed: C38.2, R10.2
unnamed: C39.1, R10.1, R12.2
unnamed: C41.1, R14.1
unnamed: C41.2, J8.5
unnamed: J8.4, R12.1, R13.2
unnamed: J8.6, K1.4
unnamed: J8.7, K1.3
unnamed: Q1.2 (B), R11.1
unnamed: D2.1, K1.2, Q1.3 (E)
unnamed: C42.1, R16.2, R17.1, R18.2, U28.2 (IN+)
unnamed: R14.2, R15.1, R16.1, U28.3 (IN-)
VCC: C40.1, D2.2, K1.1, R9.2, R15.2, R17.2, U28.8 (VCC); also elsewhere on the board

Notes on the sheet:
Cassette in (read)
Cassette out (write)
REM+
REM-

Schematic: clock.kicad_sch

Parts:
C19, C20: 100nF; C_Disc_D5.0mm_W2.5mm_P2.50mm
U6: 74HC08; DIP-14_W7.62mm
U8: 74HC74; DIP-14_W7.62mm
Y1: SG-531; Oscillator_SeikoEpson_SG-8002DC

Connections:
/CLK: U6.11, U8.3 (CP); also elsewhere on the board
/PSGCLK: U8.5 (Q); also elsewhere on the board
GND: C19.2, C20.2, U8.7 (GND), Y1.4 (GND); also elsewhere on the board
unnamed: U8.2 (D), U8.6 (~Q)
unnamed: U6.13, Y1.5 (OUT)
VCC: C19.1, C20.1, U6.12, U8.1 (~RD), U8.4 (~SD), U8.14 (VCC), Y1.1 (OE), Y1.8 (Vcc); also elsewhere on the board

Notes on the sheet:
Buffered clock signal using a spare 7408 AND-gate

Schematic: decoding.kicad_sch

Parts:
C1, C2, C3, C4, C5, C6: 100nF; C_Disc_D5.0mm_W2.5mm_P2.50mm
U1: 74HC04; DIP-14_W7.62mm
U2, U3, U4: 74HC32; DIP-14_W7.62mm
U5: 74HC139; DIP-16_W7.62mm
U6: 74HC08; DIP-14_W7.62mm
U7: 74HC138; DIP-16_W7.62mm
U8: 74HC74; DIP-14_W7.62mm

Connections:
/ADDR0: U3.9; also elsewhere on the board
/ADDR1: U1.3, U3.13; also elsewhere on the board
/ADDR3: U7.1 (A0); also elsewhere on the board
/ADDR4: U7.2 (A1); also elsewhere on the board
/ADDR5: U7.3 (A3); also elsewhere on the board
/ADDR6: U2.2; also elsewhere on the board
/ADDR7: U1.9; also elsewhere on the board
/ADDR14: U5.14 (A0); also elsewhere on the board
/ADDR15: U1.1, U3.2, U5.13 (A1); also elsewhere on the board
/DATADIR: U6.3; also elsewhere on the board
/DECODING/~PPISL: U4.5, U4.9, U7.10 (~Y5), U8.10 (~SD)
/DECODING/~PSGBDIR: U1.13, U3.11, U6.10
/DECODING/~PSGRD: U2.5, U2.8
/DECODING/~PSGSL: U2.10, U2.12, U7.11 (~Y4)
/DECODING/~PSGWR: U2.11, U3.12
/PSGBC1: U1.10; also elsewhere on the board
/PSGBDIR: U1.12; also elsewhere on the board
/~CS1: U5.11 (~Y1), U6.4; also elsewhere on the board
/~CS2: U5.10 (~Y2), U6.5; also elsewhere on the board
/~CS12: U6.6; also elsewhere on the board
/~IORQ: U4.1, U7.5 (~E2); also elsewhere on the board
/~M1: U4.2, U7.6 (E3); also elsewhere on the board
/~MREQ: U4.12; also elsewhere on the board
/~PPIRDY: U8.8 (~Q); also elsewhere on the board
/~PPIRD: U4.6; also elsewhere on the board
/~PPIWR: U4.8; also elsewhere on the board
/~RAMSL0: U3.6; also elsewhere on the board
/~RAMSL1: U3.3; also elsewhere on the board
/~RD: U2.9, U4.4, U5.15 (~OE), U6.1; also elsewhere on the board
/~RESET: U8.13 (~RD); also elsewhere on the board
/~RFSH: U1.5; also elsewhere on the board
/~SLTSL1: U3.1, U3.4; also elsewhere on the board
/~SLTSLEN: U4.11; also elsewhere on the board
/~VDPSL: U7.12 (~Y3); also elsewhere on the board
/~WR: U2.13, U4.10; also elsewhere on the board
GND: C1.2, C2.2, C3.2, C4.2, C5.2, C6.2, U1.7 (GND), U2.7 (GND), U3.7 (GND), U4.7 (GND), U6.7 (GND), U7.8 (GND), U8.11 (CP), U8.12 (D); also elsewhere on the board
unnamed: U1.2, U3.5
unnamed: U1.4, U2.4
unnamed: U1.6, U4.13
unnamed: U1.8, U2.1
unnamed: U1.11, U3.8
unnamed: U2.6, U6.9
unnamed: U3.10, U6.8
unnamed: U4.3, U6.2
unnamed: U2.3, U7.4 (~E1)
VCC: C1.1, C2.1, C3.1, C4.1, C5.1, C6.1, U1.14 (VCC), U2.14 (VCC), U3.14 (VCC), U4.14 (VCC), U6.14 (VCC), U7.16 (VCC); also elsewhere on the board

Board: 2 copper layers, 128 parts (0 on the bottom side), 203 nets, no tracks yet.

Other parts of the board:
H1, H2, H3, H4, H5, H6, H7, H8, H9, H10, H11: MountingHole_3.2mm_M3_DIN965_Pad
H12, H13, H14, H15, H16, H17: MountingHole_3.2mm_M3_DIN965

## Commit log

2026-06-02 Update to KiCad v10 and use plugin-based Artemisa libs
    [cassette.kicad_sch, clock.kicad_sch, cpu.kicad_sch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]
2026-06-02 Add enclosure CAD files for 3D printing
2026-06-24 Fix GFX9918 backplate connector
2026-07-12 Rename project
    [cassette.kicad_sch, clock.kicad_sch, cpu.kicad_sch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]
2026-07-12 Introduce PoR using MIC1232
    [cassette.kicad_sch, clock.kicad_sch, cpu.kicad_sch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]
2026-07-14 Prepare schematic for JST power input
    [power.kicad_sch]
2026-08-25 Use clock generator IC instead of oscillator
    [cassette.kicad_sch, clock.kicad_sch, power.kicad_sch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]
2026-08-25 Fix wrong refences to symbols library
    [cassette.kicad_sch]
2026-08-25 Re-annotate the whole schematic
    [cassette.kicad_sch, clock.kicad_sch, cpu.kicad_sch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]
2026-08-25 Resolve power connector pinout
    [clock.kicad_sch, power.kicad_sch]
2026-08-25 Clenaup PCB layout
    [motherboard-hk10.kicad_pcb]
2026-08-25 Set PCB margin and design rules values
    [motherboard-hk10.kicad_pcb]
2026-08-26 Adjust footprints and draft PCB layout
    [cassette.kicad_sch, clock.kicad_sch, cpu.kicad_sch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]
2026-08-26 Add mounting holes to the PCB
    [motherboard-hk10.kicad_pcb]
2026-08-27 Fix PCB layout
    [motherboard-hk10.kicad_pcb]
2026-08-27 Connect 12V/-12V rails to slots
    [motherboard-hk10.kicad_pcb, slots.kicad_sch]

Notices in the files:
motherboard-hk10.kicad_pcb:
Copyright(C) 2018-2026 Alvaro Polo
